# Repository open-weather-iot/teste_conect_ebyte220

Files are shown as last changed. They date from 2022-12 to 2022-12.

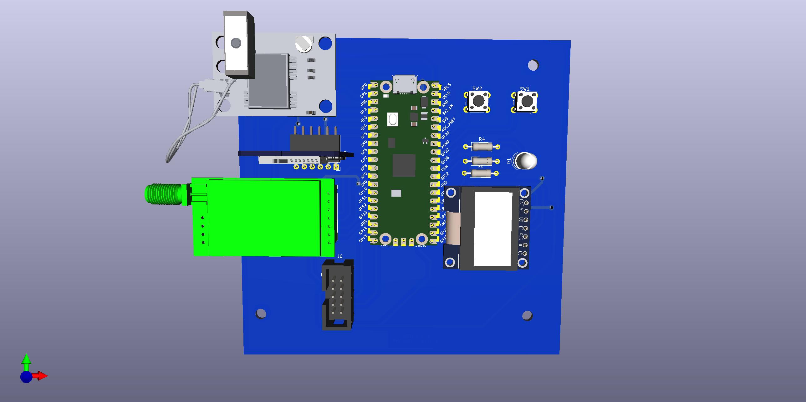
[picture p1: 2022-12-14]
Hardware/Circuito esquemático transmissor/pcb final.jpg

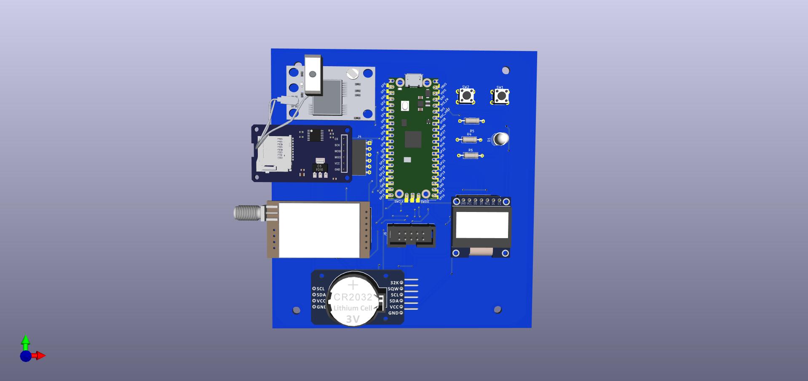
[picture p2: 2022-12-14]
Hardware/Circuito esquemático transmissor/pcb 1.jpg

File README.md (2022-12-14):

# teste_conect_ebyte220
Neste repositório será armazenado os códigos para teste de cobertura rádio utilizando o módulo E220 do fabricante Ebyte

As bibliotecas utilizadas foram:
RP2040_SD para o cartão de memória, Ebyte para o módulo LoRa E220, Tiny GPS para o módulo GPS, Adafruit GFX e Adafruit SSD1306 para o display oled 
SPI.

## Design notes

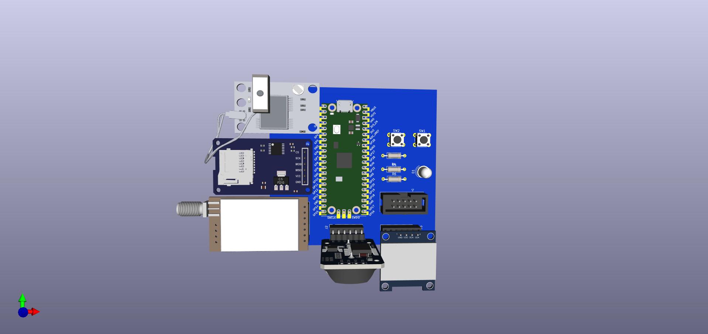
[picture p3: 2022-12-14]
Hardware/Circuito esquemático transmissor/pcb top.jpg

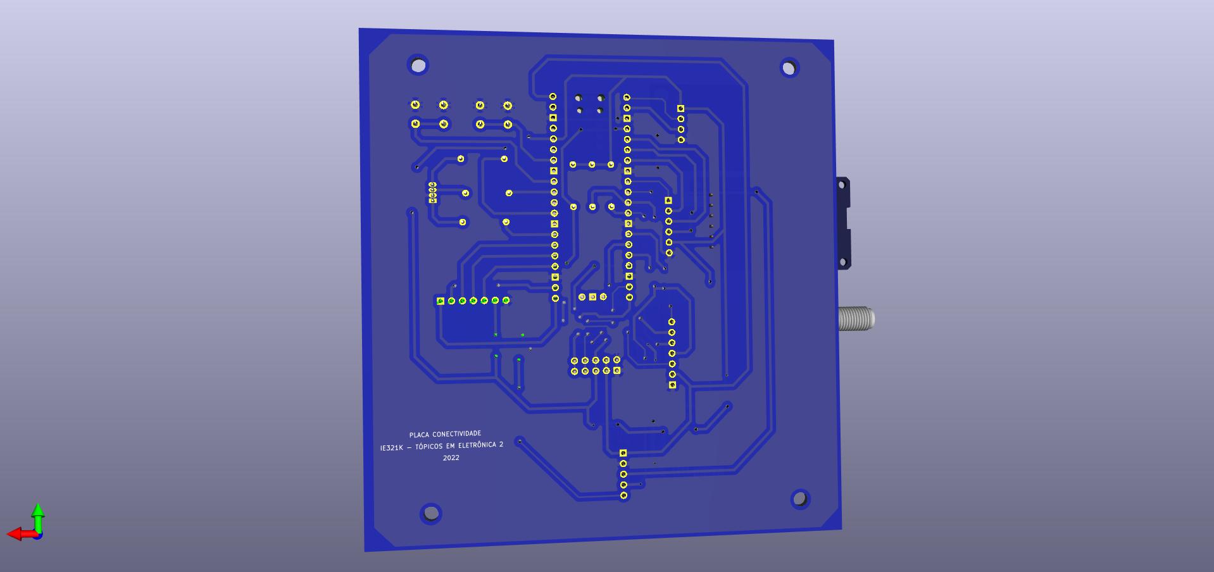
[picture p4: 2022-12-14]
Hardware/Circuito esquemático transmissor/PLACA BOT.jpg

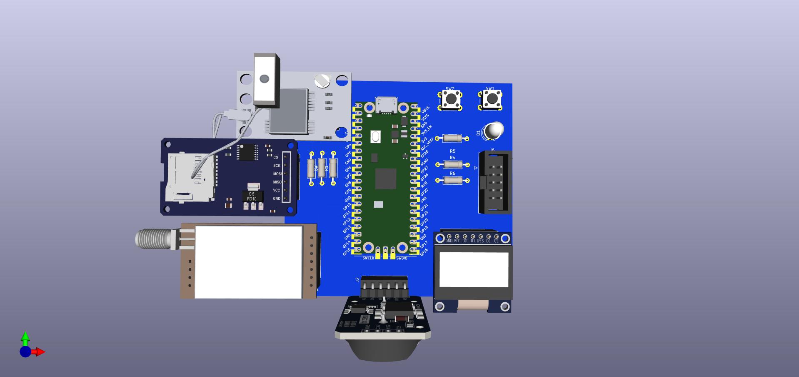
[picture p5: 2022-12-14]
Hardware/Circuito esquemático Receptor/Circuito esquemático1.jpg

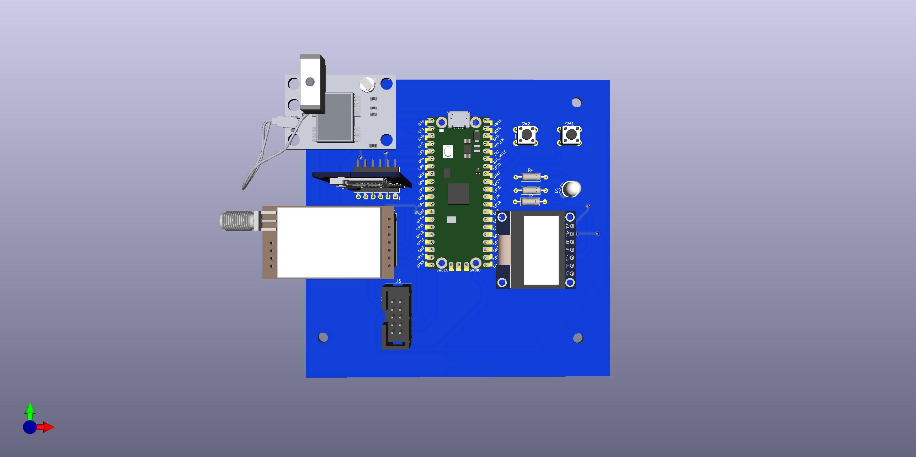
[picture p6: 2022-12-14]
Hardware/Circuito esquemático transmissor/placa vfinal.jpg

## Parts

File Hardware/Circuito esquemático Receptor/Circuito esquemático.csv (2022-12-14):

Source: | C:\Users\Eng. Daniel Vieira\Desktop\Projeto Estação meteorológica (Conectividade)\Circuito esquemático\Circuito esquemático.kicad_sch
Date: | 11/11/2022 16:41:23
Tool: | Eeschema (6.0.1)
Generator: | C:\Program Files\KiCad\6.0\bin\scripting\plugins/bom_csv_grouped_by_value.py
Component Count: | 15
Individual Components:
Item | Qty | Reference(s) | Value | LibPart | Footprint | Datasheet
 |  | D1 | LED_RKBG | Device:LED_RKBG | LED_THT:LED_D5.0mm-4_RGB | ~
 |  | J1 | Conn_01x07_Female | Connector:Conn_01x07_Female | Connector_PinSocket_2.54mm:PinSocket_1x07_P2.54mm_Vertical | ~
 |  | J3 | Conn_01x04_Female | Connector:Conn_01x04_Female | Connector_PinSocket_2.54mm:PinSocket_1x04_P2.54mm_Vertical | ~
 |  | J4 | Conn_01x06_Female | Connector:Conn_01x06_Female | Connector_PinSocket_2.54mm:PinSocket_1x06_P2.54mm_Horizontal | ~
 |  | J5 | Conn_01x07_Female | Connector:Conn_01x07_Female | Connector_PinSocket_2.54mm:PinSocket_1x07_P2.54mm_Vertical | ~
 |  | J6 | Conn_02x05_Counter_Clockwise | Connector_Generic:Conn_02x05_Counter_Clockwise | Connector_IDC:IDC-Header_2x05_P2.54mm_Vertical | ~
 |  | R1 | 10K | Device:R | Resistor_THT:R_Axial_DIN0207_L6.3mm_D2.5mm_P10.16mm_Horizontal | ~
 |  | R2 | 10K | Device:R | Resistor_THT:R_Axial_DIN0207_L6.3mm_D2.5mm_P10.16mm_Horizontal | ~
 |  | R3 | 10K | Device:R | Resistor_THT:R_Axial_DIN0207_L6.3mm_D2.5mm_P10.16mm_Horizontal | ~
 |  | R4 | 220R | Device:R | Resistor_THT:R_Axial_DIN0207_L6.3mm_D2.5mm_P10.16mm_Horizontal | ~
 |  | R5 | 220R | Device:R | Resistor_THT:R_Axial_DIN0207_L6.3mm_D2.5mm_P10.16mm_Horizontal | ~
 |  | R6 | 220R | Device:R | Resistor_THT:R_Axial_DIN0207_L6.3mm_D2.5mm_P10.16mm_Horizontal | ~
 |  | SW1 | SW_Push | Switch:SW_Push | Button_Switch_THT:SW_PUSH_6mm | ~
 |  | SW2 | SW_Push | Switch:SW_Push | Button_Switch_THT:SW_PUSH_6mm | ~
 |  | U1 | Pico | Raspberry Pi Pico:Pico | MCU_RaspberryPi_and_Boards:RPi_Pico_SMD_TH
Collated Components:
Item | Qty | Reference(s) | Value | LibPart | Footprint | Datasheet
1 | 1 | D1 | LED_RKBG | Device:LED_RKBG | LED_THT:LED_D5.0mm-4_RGB | ~
2 | 2 | J1, J5 | Conn_01x07_Female | Connector:Conn_01x07_Female | Connector_PinSocket_2.54mm:PinSocket_1x07_P2.54mm_Vertical | ~
3 | 1 | J3 | Conn_01x04_Female | Connector:Conn_01x04_Female | Connector_PinSocket_2.54mm:PinSocket_1x04_P2.54mm_Vertical | ~
4 | 1 | J4 | Conn_01x06_Female | Connector:Conn_01x06_Female | Connector_PinSocket_2.54mm:PinSocket_1x06_P2.54mm_Horizontal | ~
5 | 1 | J6 | Conn_02x05_Counter_Clockwise | Connector_Generic:Conn_02x05_Counter_Clockwise | Connector_IDC:IDC-Header_2x05_P2.54mm_Vertical | ~
6 | 3 | R1, R2, R3 | 10K | Device:R | Resistor_THT:R_Axial_DIN0207_L6.3mm_D2.5mm_P10.16mm_Horizontal | ~
7 | 3 | R4, R5, R6 | 220R | Device:R | Resistor_THT:R_Axial_DIN0207_L6.3mm_D2.5mm_P10.16mm_Horizontal | ~
8 | 2 | SW1, SW2 | SW_Push | Switch:SW_Push | Button_Switch_THT:SW_PUSH_6mm | ~
9 | 1 | U1 | Pico | Raspberry Pi Pico:Pico | MCU_RaspberryPi_and_Boards:RPi_Pico_SMD_TH

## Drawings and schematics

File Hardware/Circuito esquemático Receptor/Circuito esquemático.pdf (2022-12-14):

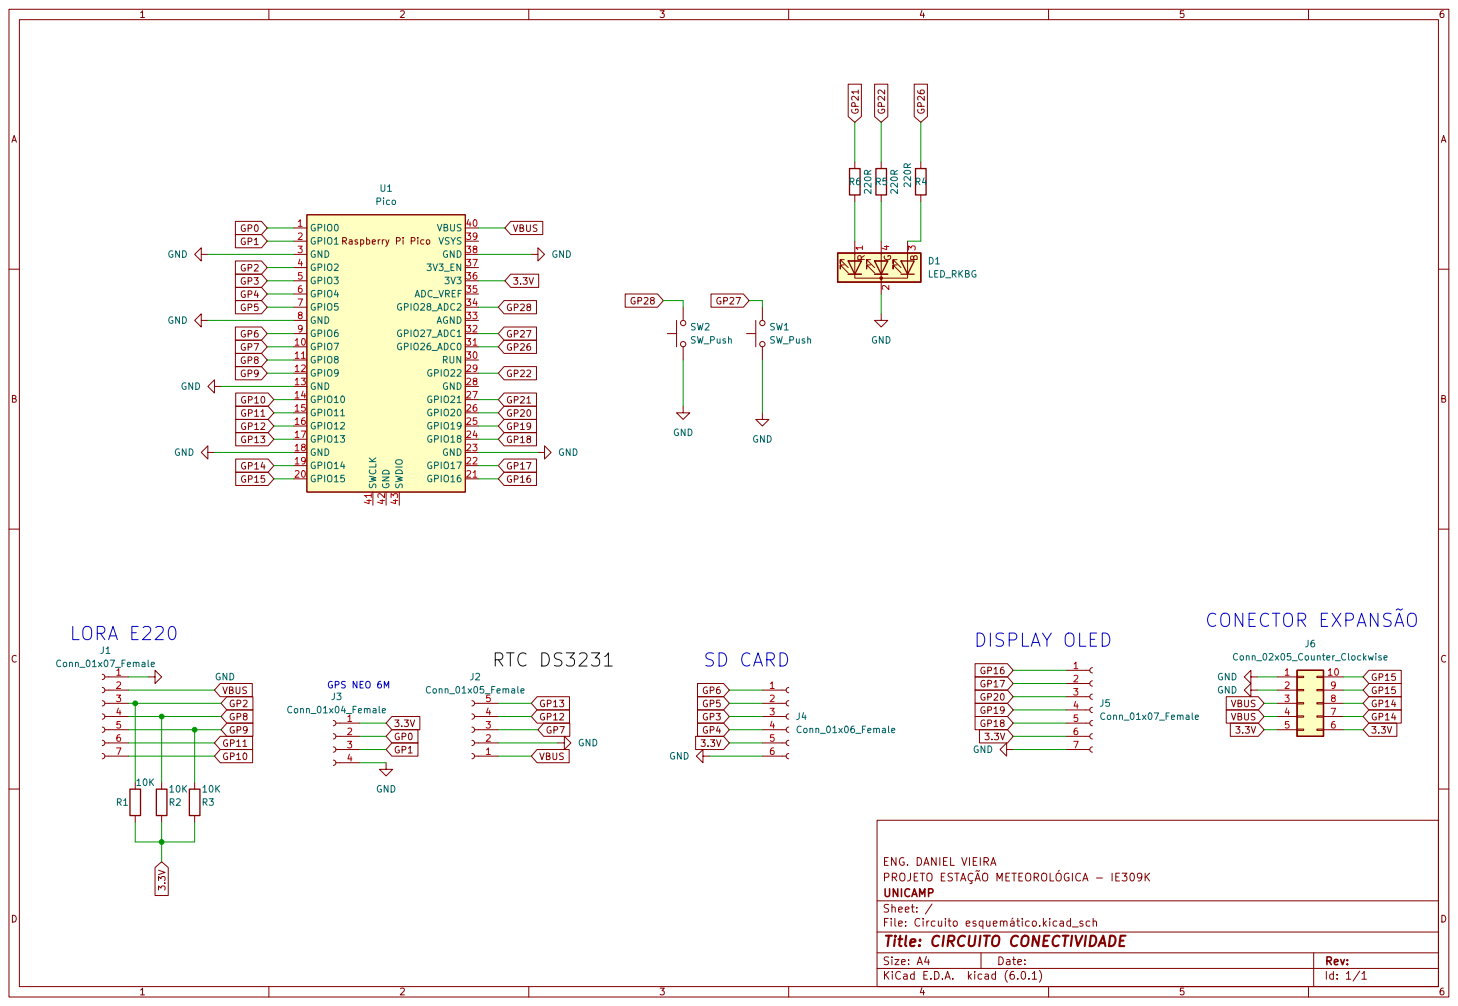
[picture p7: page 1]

Id: 1/1 Title: CIRCUITO CONECTIVIDADE

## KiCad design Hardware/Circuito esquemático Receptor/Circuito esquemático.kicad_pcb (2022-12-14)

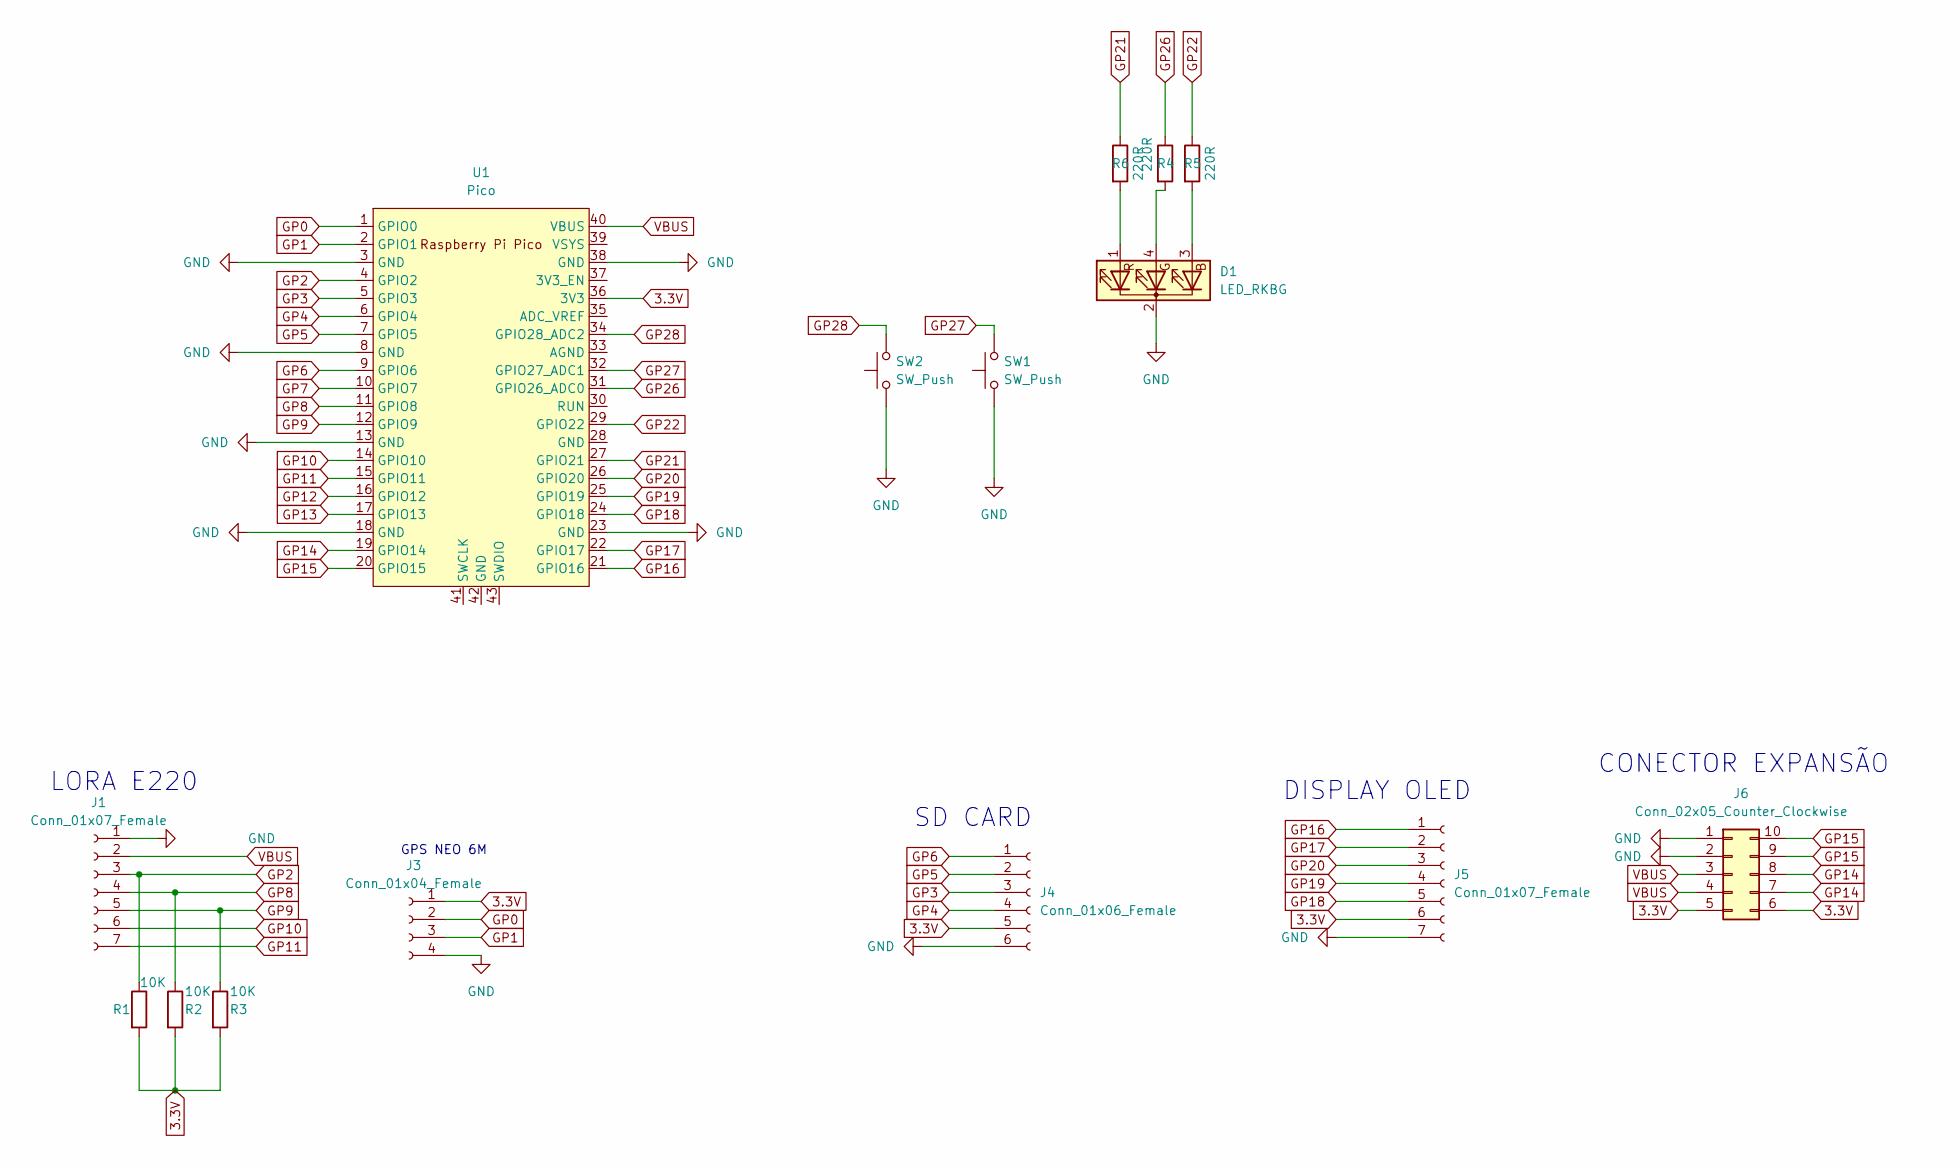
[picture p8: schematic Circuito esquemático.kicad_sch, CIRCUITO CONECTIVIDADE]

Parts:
D1: LED_RKBG; LED_D5.0mm-4_RGB
J1, J5: Conn_01x07_Female; PinSocket_1x07_P2.54mm_Vertical
J3: Conn_01x04_Female; PinSocket_1x04_P2.54mm_Vertical
J4: Conn_01x06_Female; PinSocket_1x06_P2.54mm_Horizontal
J6: Conn_02x05_Counter_Clockwise; IDC-Header_2x05_P2.54mm_Vertical
R1, R2, R3: 10K; R_Axial_DIN0207_L6.3mm_D2.5mm_P10.16mm_Horizontal
R4, R5, R6: 220R; R_Axial_DIN0207_L6.3mm_D2.5mm_P10.16mm_Horizontal
SW1, SW2: SW_Push; SW_PUSH_6mm
U1: Pico; RPi_Pico_SMD_TH

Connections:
3.3V: J3.1, J4.5, J5.6, J6.5, J6.6, R1.2, R2.2, R3.2, U1.36 (3V3)
GND: D1.2 (K), J1.1, J3.4, J4.6, J5.7, J6.1, J6.2, SW1.1, SW2.1, U1.3 (GND), U1.8 (GND), U1.13 (GND), U1.18 (GND), U1.23 (GND), U1.38 (GND)
GP0: J3.2, U1.1 (GPIO0)
GP1: J3.3, U1.2 (GPIO1)
GP2: J1.3, R1.1, U1.4 (GPIO2)
GP3: J4.3, U1.5 (GPIO3)
GP4: J4.4, U1.6 (GPIO4)
GP5: J4.2, U1.7 (GPIO5)
GP6: J4.1, U1.9 (GPIO6)
GP7: U1.10 (GPIO7)
GP8: J1.4, R2.1, U1.11 (GPIO8)
GP9: J1.5, R3.1, U1.12 (GPIO9)
GP10: J1.6, U1.14 (GPIO10)
GP11: J1.7, U1.15 (GPIO11)
GP12: U1.16 (GPIO12)
GP13: U1.17 (GPIO13)
GP14: J6.7, J6.8, U1.19 (GPIO14)
GP15: J6.9, J6.10, U1.20 (GPIO15)
GP16: J5.1, U1.21 (GPIO16)
GP17: J5.2, U1.22 (GPIO17)
GP18: J5.5, U1.24 (GPIO18)
GP19: J5.4, U1.25 (GPIO19)
GP20: J5.3, U1.26 (GPIO20)
GP21: R6.1, U1.27 (GPIO21)
GP22: R5.1, U1.29 (GPIO22)
GP26: R4.1, U1.31 (GPIO26_ADC0)
GP27: SW1.2, U1.32 (GPIO27_ADC1)
GP28: SW2.2, U1.34 (GPIO28_ADC2)
unnamed: D1.1 (RA), R6.2
unnamed: D1.3 (BA), R5.2
unnamed: D1.4 (GA), R4.2
VBUS: J1.2, J6.3, J6.4, U1.40 (VBUS)

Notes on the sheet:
CONECTOR EXPANSÃO
GPS NEO 6M
DISPLAY OLED
LORA E220
SD CARD

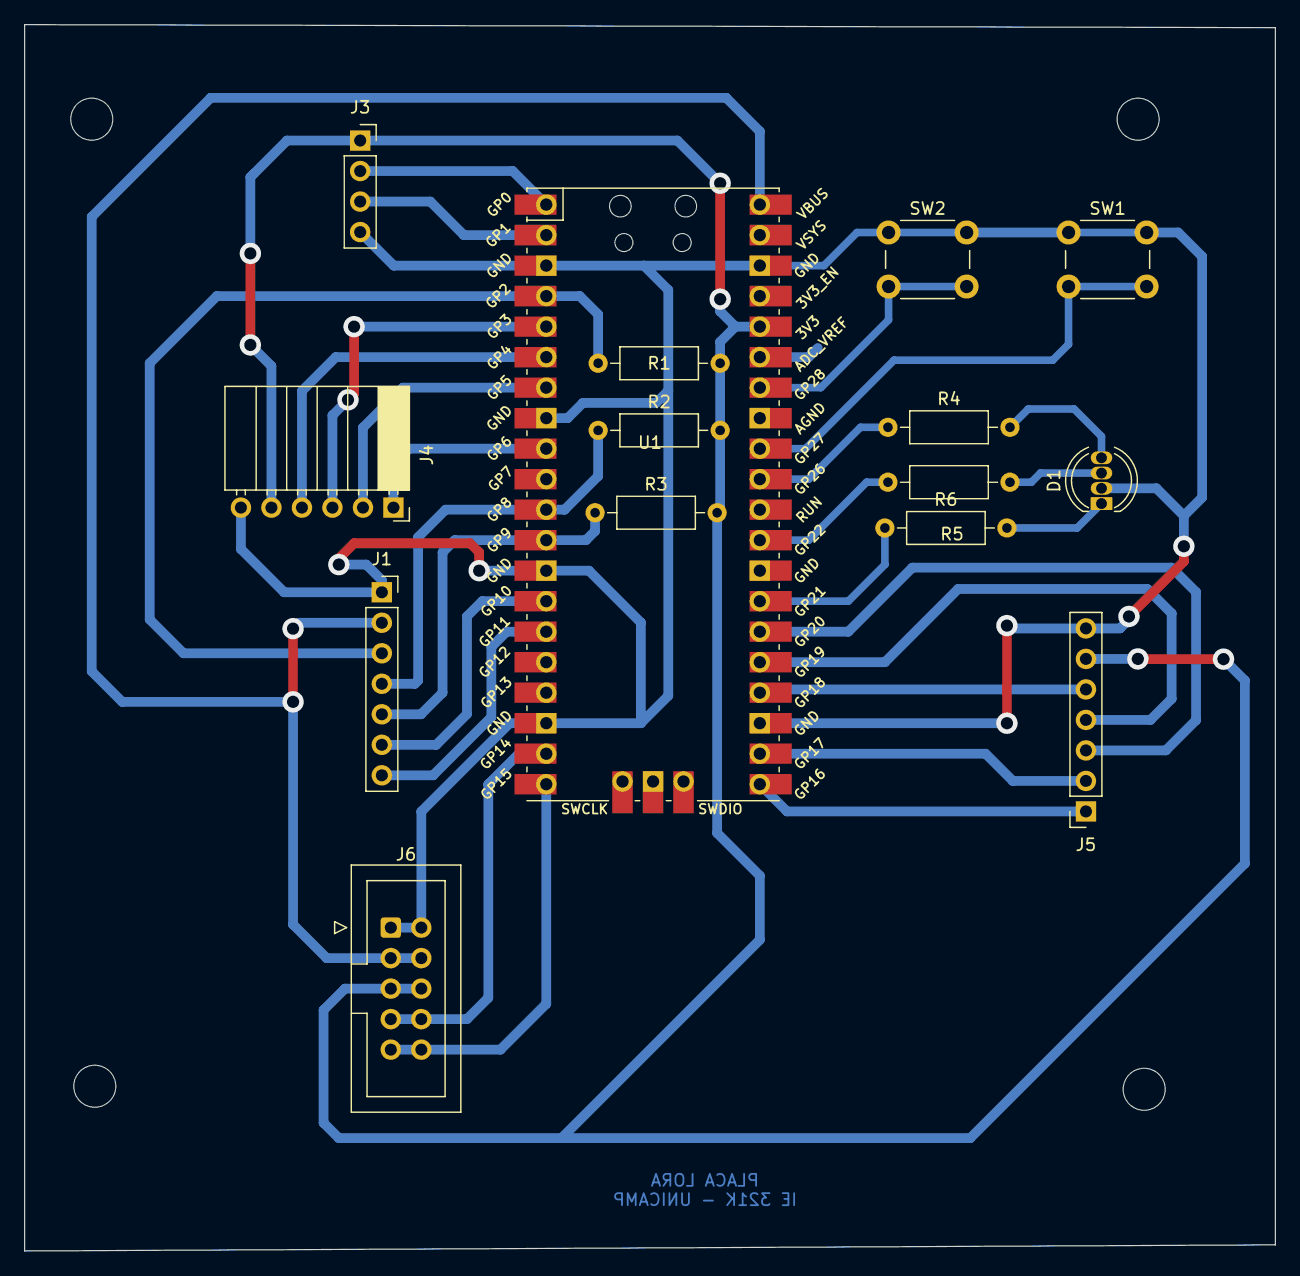
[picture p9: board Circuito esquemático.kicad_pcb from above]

Board: 2 copper layers, 104.1 x 102.1 mm, 15 parts (0 on the bottom side), 29 nets.

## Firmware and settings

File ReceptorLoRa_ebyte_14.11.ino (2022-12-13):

/*
Firmware LoRa com Rasp Pico W e módulo E220
14/11/2022
Receptor
M0 - 0
M1 -1
*/
#include "Arduino.h"
#include "LoRa_E220.h"
#include <SPI.h>
#include <RP2040_SD.h>
#include <Wire.h>
#include <Adafruit_GFX.h>
#include <Adafruit_SSD1306.h>
#include <TinyGPS.h>

#define ss Serial1
String Rssi, latitude, longitude;
TinyGPS gps;

#define PIN_SD_MOSI       19
  #define PIN_SD_MISO       16
  #define PIN_SD_SCK        18
  #define PIN_SD_SS         17
#define SCREEN_WIDTH 128 // OLED display width, in pixels
#define SCREEN_HEIGHT 64 // OLED display height, in pixels

// Declaration for SSD1306 display connected using software SPI (default case):
#define OLED_MOSI  7 // sda
#define OLED_CLK    6 // sck display 
#define OLED_DC    3 // dc
#define OLED_CS    4 // cs display
#define OLED_RESET 15 // res
Adafruit_SSD1306 display(SCREEN_WIDTH, SCREEN_HEIGHT,
  OLED_MOSI, OLED_CLK, OLED_DC, OLED_RESET, OLED_CS);

#define NUMFLAKES     10 // Number of snowflakes in the animation example

#define LOGO_HEIGHT   16
#define LOGO_WIDTH    16

// ---------- Raspberry PI Pico pins --------------
 LoRa_E220 e220ttl(&Serial2, 2, 10, 11); //  RX AUX M0 M1
// -------------------------------------

float flat, flon,data,hora;
int year;
byte month, day, hour, minute, second, hundredths;

void setup() {
  Serial.begin(9600);
 ss.begin(9600);

  // Startup all pins and UART
  e220ttl.begin();

  Serial.println("Start receiving!");
  pinMode(10,OUTPUT);
  pinMode(11,OUTPUT);
  digitalWrite(10,0);
  if(!display.begin(SSD1306_SWITCHCAPVCC)) {
    Serial.println(F("SSD1306 allocation failed"));
    for(;;); // Don't proceed, loop forever
  }
   display.clearDisplay();
   Serial.println(TinyGPS::library_version());
   
   
   Serial.print("Initializing SD card with SS = ");  Serial.println(PIN_SD_SS);
  Serial.print("SCK = ");   Serial.println(PIN_SD_SCK);
  Serial.print("MOSI = ");  Serial.println(PIN_SD_MOSI);
  Serial.print("MISO = ");  Serial.println(PIN_SD_MISO);

  if (!SD.begin(PIN_SD_SS)) 
  {
    Serial.println("Initialization failed!");
    return;
  }
  
  Serial.println("Initialization done.");
}



void loop() {
  //Serial.println("Teste");
  #define fileName  "datalog.txt"
   String dataString = "";
   File dataFile = SD.open("datalog.txt", FILE_WRITE);
   bool newData = false;
  unsigned long chars;
  unsigned short sentences, failed;
   digitalWrite(11,1);
	// If something available
  	ResponseContainer rc = e220ttl.receiveMessageRSSI();
   Serial.println("Receptor LoRa");
   Serial.print("RSSI: "); Serial.println(-(256-rc.rssi), DEC); 
   Rssi = -(256 -rc.rssi); 
   Serial.println(rc.status.getResponseDescription());
		Serial.println(rc.data);
     if (dataFile) {
   dataFile.println("Data:" + String (day) + ","+ String(month) +String(year) + "," + String
     (hour -3) +"," + String (minute) + "," + String (second) + "Rssi:" + String(Rssi));
     
     /*dataFile.println("Rssi:" + String(Rssi));
     dataFile.println( String(5)  + ",");
     */
    dataFile.close();
    // print to the serial port too:
     Serial.println("Data:" + String (day) + ","+ String(month) +String(year) + "," + String
     (hour -3) +"," + String (minute) + "," + String (second) + "Rssi:" + String(Rssi));
  }
display.clearDisplay();
  
   display.drawRoundRect(0,0, 118, 55, 0, WHITE);
  display.setTextColor(WHITE);
  display.setCursor(25,25);
  display.setTextSize(2);
  display.print("FEEC");
  display.display();
  delay(300);
  display.clearDisplay();
  display.drawRoundRect(0,0, 118, 55, 0, WHITE);
  display.setTextColor(WHITE);
  display.setTextSize(2);
  display.setCursor(5,25);
  display.print("RSSI:" + (String) Rssi);
  display.display();  
   // if the file is available, write to it:
  // For one second we parse GPS data and report some key values
  for (unsigned long start = millis(); millis() - start < 1000;)
  {
    while (ss.available())
    {
      char c = ss.read();
      // Serial.write(c); // uncomment this line if you want to see the GPS data flowing
      if (gps.encode(c)) // Did a new valid sentence come in?
        newData = true;
    }
  }

  if (newData)
  {
    
    unsigned long age;
    gps.f_get_position(&flat, &flon, &age);
    Serial.print("LAT=");
    latitude =  String(flat,5);
    Serial.print(latitude);
    Serial.print(" LON=");
    longitude =  String(flon,5);
    Serial.print(longitude);
    Serial.print(" SAT=");
    Serial.print(gps.satellites() == TinyGPS::GPS_INVALID_SATELLITES ? 0 : gps.satellites());
    Serial.print(" PREC=");
    Serial.println(gps.hdop() == TinyGPS::GPS_INVALID_HDOP ? 0 : gps.hdop());
    
    gps.crack_datetime(&year, &month, &day, &hour, &minute, &second, &hundredths, &age);
  if (age == TinyGPS::GPS_INVALID_AGE)
    Serial.print("********** ******** ");
  else
  {
    char sz[32];
    sprintf(sz, "%02d/%02d/%02d %02d:%02d:%02d ",
        day, month , year, (hour -3), minute, second);
    Serial.print(sz);
     display.clearDisplay();
  display.drawRoundRect(0, 0, 122, 60, 0, WHITE);
  display.setTextColor(WHITE);

    display.setCursor(5,10);
  display.setTextSize(1);
  display.print(String(day) + "-" + (String) month +  "-" +(String) year + " " +(String)(hour -3) +":" +(String) minute +":" +(String) second);
   display.setCursor(5,35);
  display.setTextSize(1);
  display.print("Lat:" +(String)latitude );
   display.setCursor(5,45);
  display.setTextSize(1);
  display.print("Long:" +(String) longitude );
  display.setCursor(26,25);
  display.setTextSize(2);
  display.print("-");
  display.setCursor(30,25);
  display.setTextSize(2);
  display.print(month);
  display.display();
 }

 }
  
  
  
  

     
  
  

	  // read the String message


    
  //  display.setCursor(5,25);
  //display.setTextSize(2);
  //display.print(String(95));
  //display.display();
 // display.clearDisplay();
	
 
//display.setCursor(5,25);
//  display.setTextSize(1);
 // display.print("RSSI:" + (String) Rssi);
 // display.display();  
	 // if the file is available, write to it:
 
  // if the file isn't open, pop up an error:
  
  
  }

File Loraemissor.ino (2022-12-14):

/*
Firmware LoRa com Rasp Pico W e módulo E220
14/11/2022
Transmissor
M0 - 1
M1 -0
*/
#include "Arduino.h"
#include "LoRa_E220.h"
int cont = 0;

LoRa_E220 e220ttl(&Serial2, 2, 10, 11); //  RX AUX M0 M1

void setup() {
  Serial.begin(9600);
  pinMode(10,OUTPUT);
  pinMode(11,OUTPUT);
 

 

  // INICIA O MÓDULO LORA E220
  e220ttl.begin();

  // ENVIA UM DADO DE TESTE
  Serial.println("ENVIANDO UMA MENSAGEM DE TESTE");
  //ResponseStatus rs = e220ttl.sendBroadcastFixedMessage(23, String(10,DEC);
  // Verfica se o dado foi enviado com sucesso
 // Serial.println(rs.getResponseDescription());
}

void loop() {
   digitalWrite(10,HIGH);
   digitalWrite(11,LOW);
    Serial.println("Teste LoRa EByte");
    Serial.println("Pct:" + String(cont));
  ResponseStatus rs = e220ttl.sendBroadcastFixedMessage(23, String(cont++, DEC));
  // Verfica se o dado foi enviado com sucesso
  Serial.println(rs.getResponseDescription());
  delay(200);
}

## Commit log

2022-12-14 library card sd with Raspberry Pico
2022-12-14 Projeto de hardware das placas de conectividade modulo Ebyte 220
    [Circuito esquemático-B_Cu.gbr, Circuito esquemático-B_Mask.gbr, Circuito esquemático-B_Paste.gbr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]
